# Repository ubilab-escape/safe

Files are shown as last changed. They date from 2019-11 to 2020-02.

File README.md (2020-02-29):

# Team Safe and Puzzles

## Motivation:
The Players are told to steal the Prototype from the Lab. The Prototype will be locked in the safe.

## General Idea:
After Entering the Lab Room the safe will be deactivated (red LED light). The players first have to supply the safe with power by solving a puzzle (see section puzzle).
This action will change the light color of the safes LED to orange and activate the second puzzle. This puzzle will ultimately open the safe to give access to the prototype.

## Puzzles:
### Puzzle to activate the safe: 
* Switching levers in correct position
* Find the correct resistor to generate the correct voltage

### Puzzle to open the safe:
* Riddle with numpad input

## Partlist

**part**|**count**|**price/part in €**|**price total**|**link**
:-----:|:-----:|:-----:|:-----:|:-----:
Keypad|1|5.8|5.8|[Octopart](https://octopart.com/3845-adafruit+industries-94636475?r=sp&s=QRIaZTRmSZu4F2mVarnONA)
Solenoid Lock|1|13.35|13.35|[Octopart](https://octopart.com/1512-adafruit+industries-51880349?r=sp&s=Jx9Gw6qzSH2-PR3HbMgn8w)
Banana Plug|10|2.06|20.6|[Octopart](https://octopart.com/1325-2-pomona+electronics-55397240?r=sp&s=kmyIgsMeQOCZjpt9e\_rAXw)
Banana Socket|10|1.84|18.4|[Octopart](https://octopart.com/bu-00233-0-mueller-824050?r=sp&s=FBVoi6XFSGGoTvQtIDogQw)
Piezo Buzzer|5|1.03|5.15|[Octopart](https://octopart.com/mckpt-g1711a3-05-3691-multicomp-12157125?r=sp&s=TdKAcML0QkSYqrwuZLE5lQ)
Switch|8|2.17|17.36|[Octopart](https://octopart.com/100sp1t1b4m2qe-e-switch-1058620?r=sp&s=26ppMzJ4SaadG3iCrhg9HA)
N-MOS|10|0.7|7|[Octopart](https://octopart.com/irf510pbf-vishay-46532502?r=sp&s=Ft8oBWb7Tw--a\_FmfUap9w#)
Limit switches|2|1.81|3.62|[Octopart](https://octopart.com/db1c-b1lb-zf-71118816?r=sp&s=sDTxIuqxSJOc-Uf9S2HFEg)
Wooden chest|1|18|18|[Obi](https://www.obi.de/aufbewahrungsboxen/laublust-holzkiste-deckel-und-griffe-natur-kiefer-40-cm-x-30-cm-x-24-cm-fsc-/p/4480497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)
Total: 109.28 €

## Group

Markus Schwörer, Florian Bregler, Frank Mutter

## Protocol to control leds and piezo via mqtt

standart JSON message on topic 5/safe/control with data = "x:y". x is color and y is the mode.

Colors (x):
* LED_COLOR_WHITE 0
* LED_COLOR_RED 1
* LED_COLOR_GREEN 2
* LED_COLOR_BLUE  3
* LED_COLOR_ORANGE 4

Mode (y):
* LED_MODE_ON 0
* LED_MODE_OFF 1
* LED_MODE_PULSE 2
* LED_MODE_BLINK 3
* LED_MODE_PIEZO 9

For LED_MODE_PIEZO the color parameter is the time of the buzzer sound in seconds.

examples:
* "{\"method\": \"trigger\", \"state\": \"on\", \"data\": \"3:0\" }"
=> Turns blue LEDs on.
* "{\"method\": \"trigger\", \"state\": \"on\", \"data\": \"4:3\" }"
=> LEDs orange blinking.
* "{\"method\": \"trigger\", \"state\": \"on\", \"data\": \"5:9\" }"
=> Buzzer sound for 5 seconds (max value: 9)

## Schematics

### Safe Activate
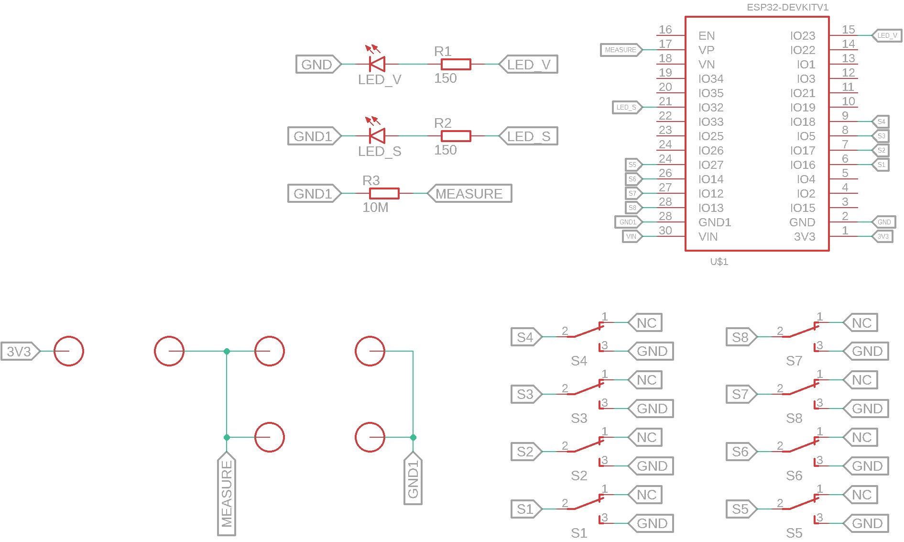
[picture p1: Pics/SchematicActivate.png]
Safe Activate Schematic

**Image 1**: Schematic of the activation.

### Safe Control
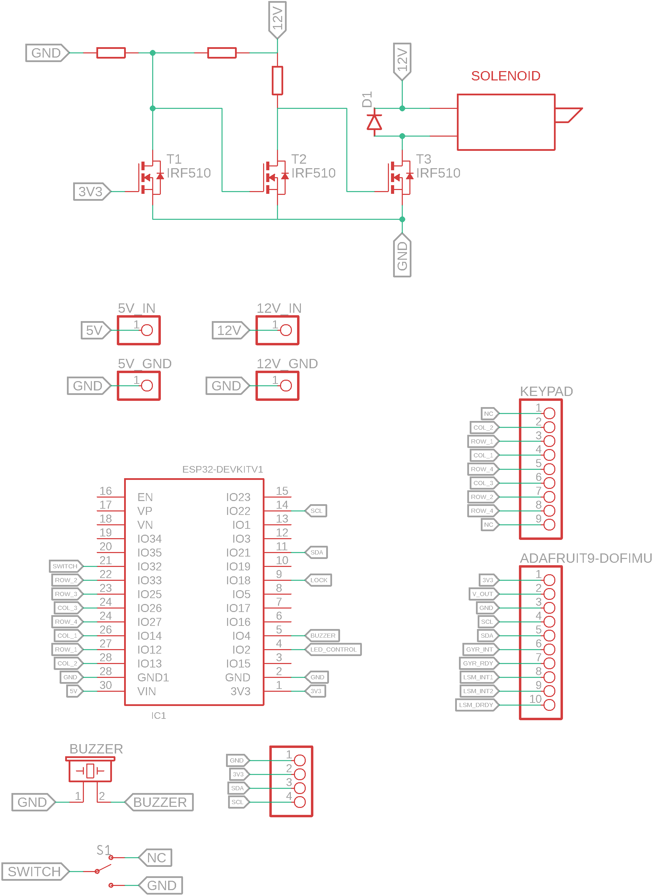
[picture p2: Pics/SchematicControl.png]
Safe Control Schematic

**Image 2**: Schematic of the safe.

## Flow Charts

### Safe Activate

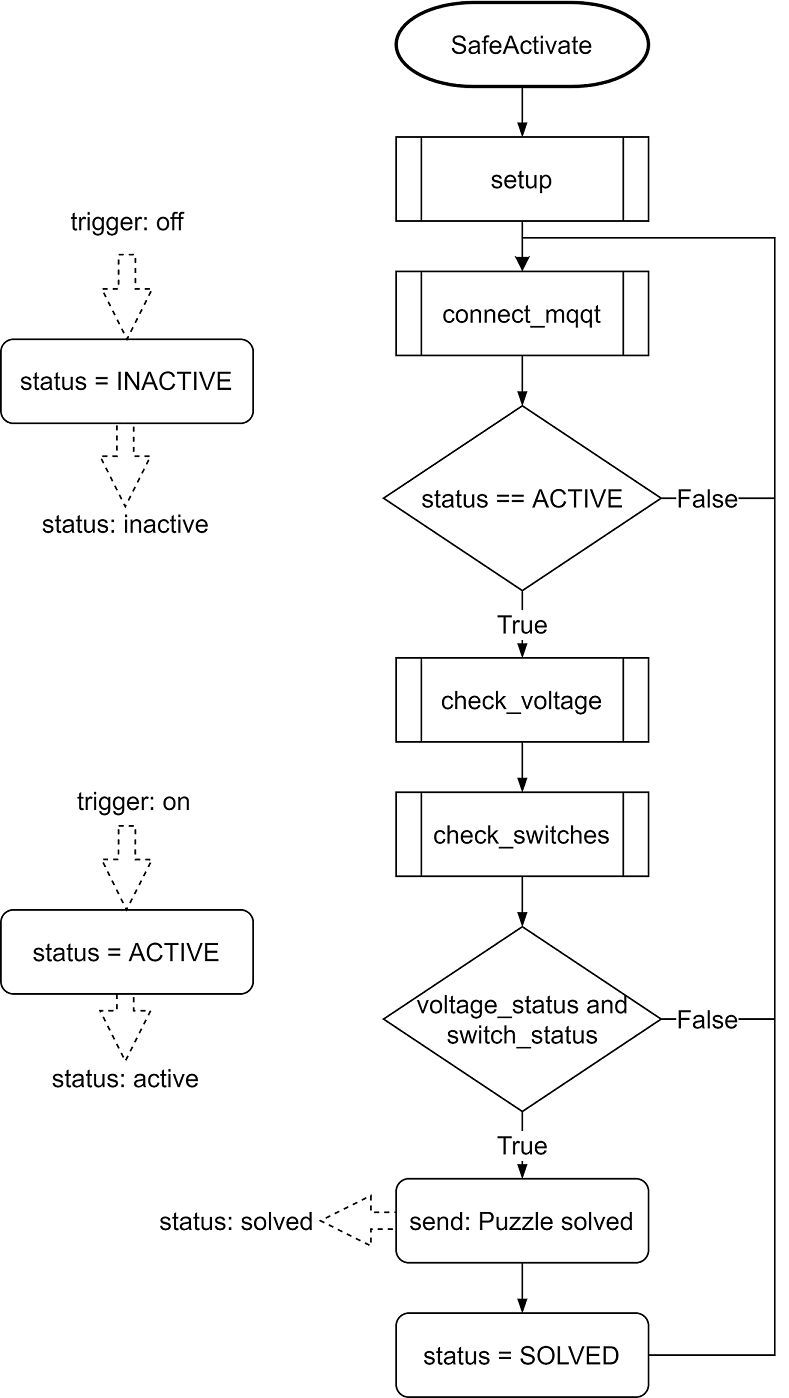
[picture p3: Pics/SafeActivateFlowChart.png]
Safe Activate Flow Chart


**Image 3**: Flow Chart of the safe activation

### Safe Control

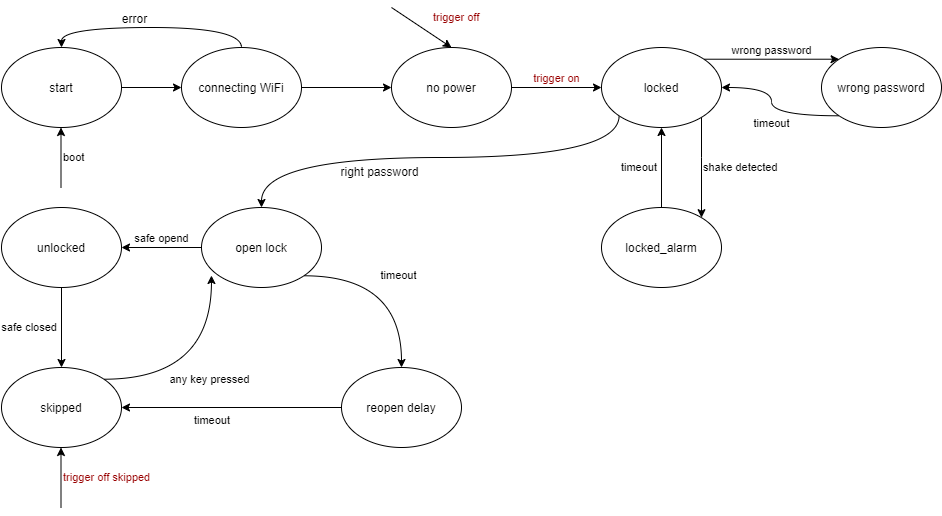
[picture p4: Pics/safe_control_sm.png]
Safe Control State Machine

**Image 4**: State machine of the safe control with the main states

## Instructions for the Escape Room Operator

### Room Reset:
* Close the safe 
* Pull out the resistors and place them in front of the puzzle
* Put the safe datasheet (back) on the table

# Pictures

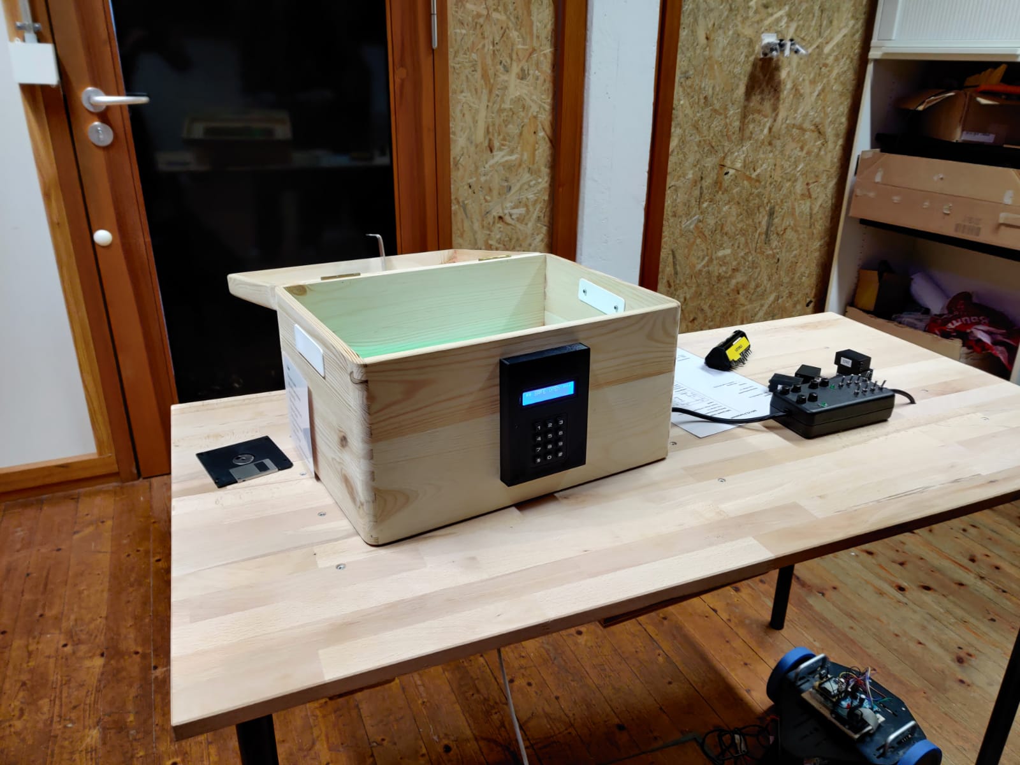
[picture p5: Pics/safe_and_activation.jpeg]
Safe and activation picture

**Image 5**: Picture of the safe (left) and the activatioin puzzle (right).

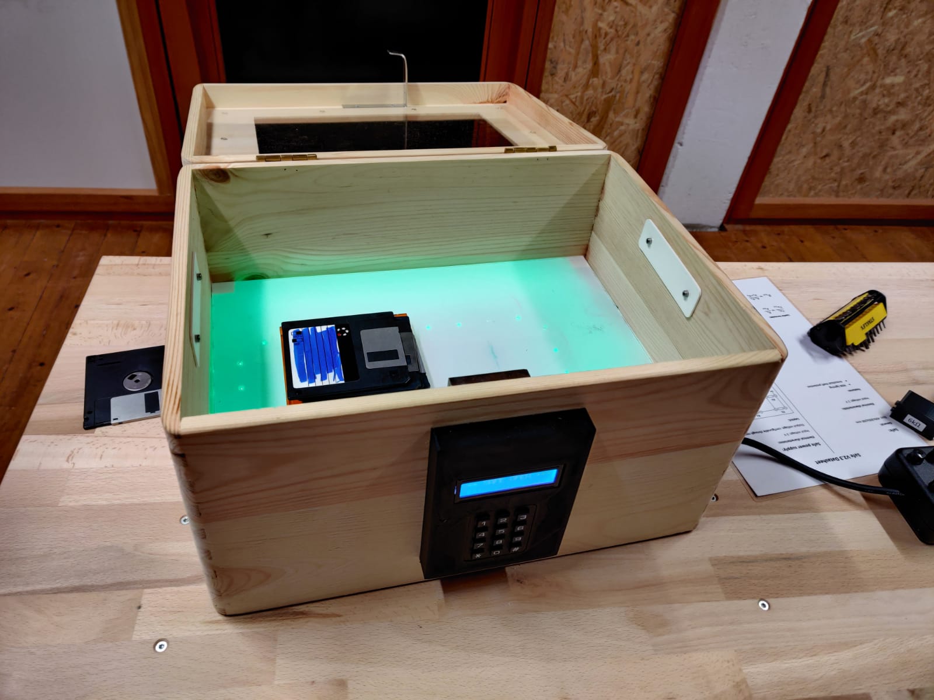
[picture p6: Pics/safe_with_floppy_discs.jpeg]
Safe with floppy discs

**Image 6**: Picture of the Safe with green LED color and floppy discs inside.

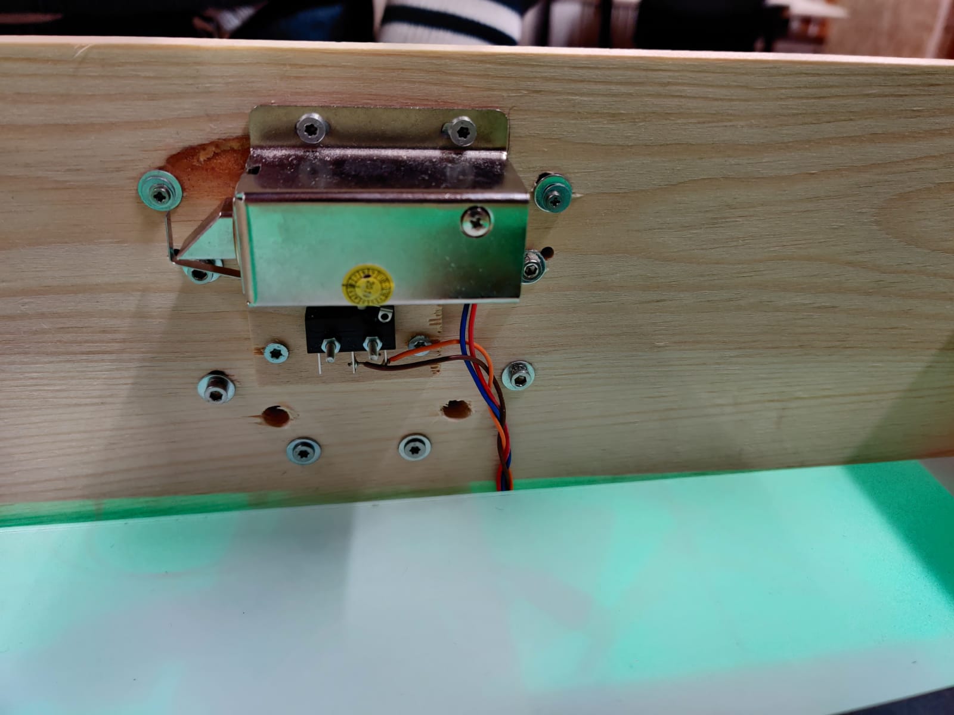
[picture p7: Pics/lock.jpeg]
lock with switch

**Image 7**: Picture of the lock with switch to detect whether the safe is opened or closed.

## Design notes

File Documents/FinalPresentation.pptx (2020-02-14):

## Group 5: Safe

Frank Mutter, Markus Schwörer, Florian Bregler

## Motivation

- Main story goal:
Players have to steal the Prototypes
- Safe:
Open safe → Get Prototypes

## Safe puzzle

- Divided into two parts:
1. Safe activation:
  - Voltage divider puzzle
  - Switch puzzle
2. Safe opening:
  - Code combination puzzle

## Safe activation

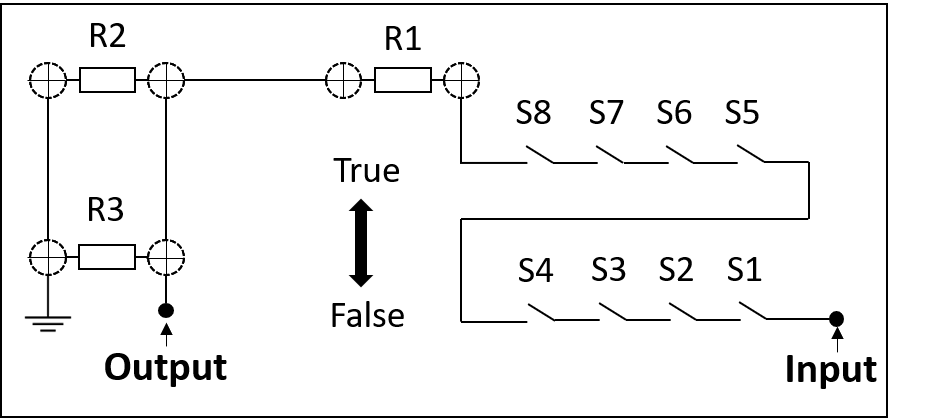
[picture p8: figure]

- Set switch position according to data sheet
- Divide input voltage using resistors

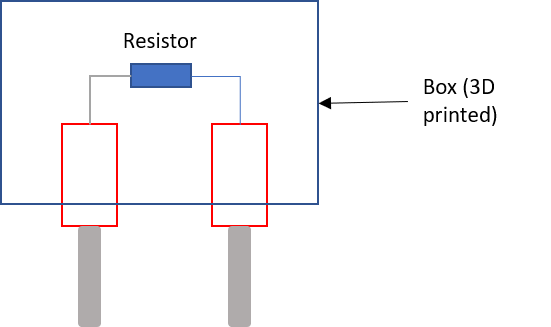
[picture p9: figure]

## Safe activation

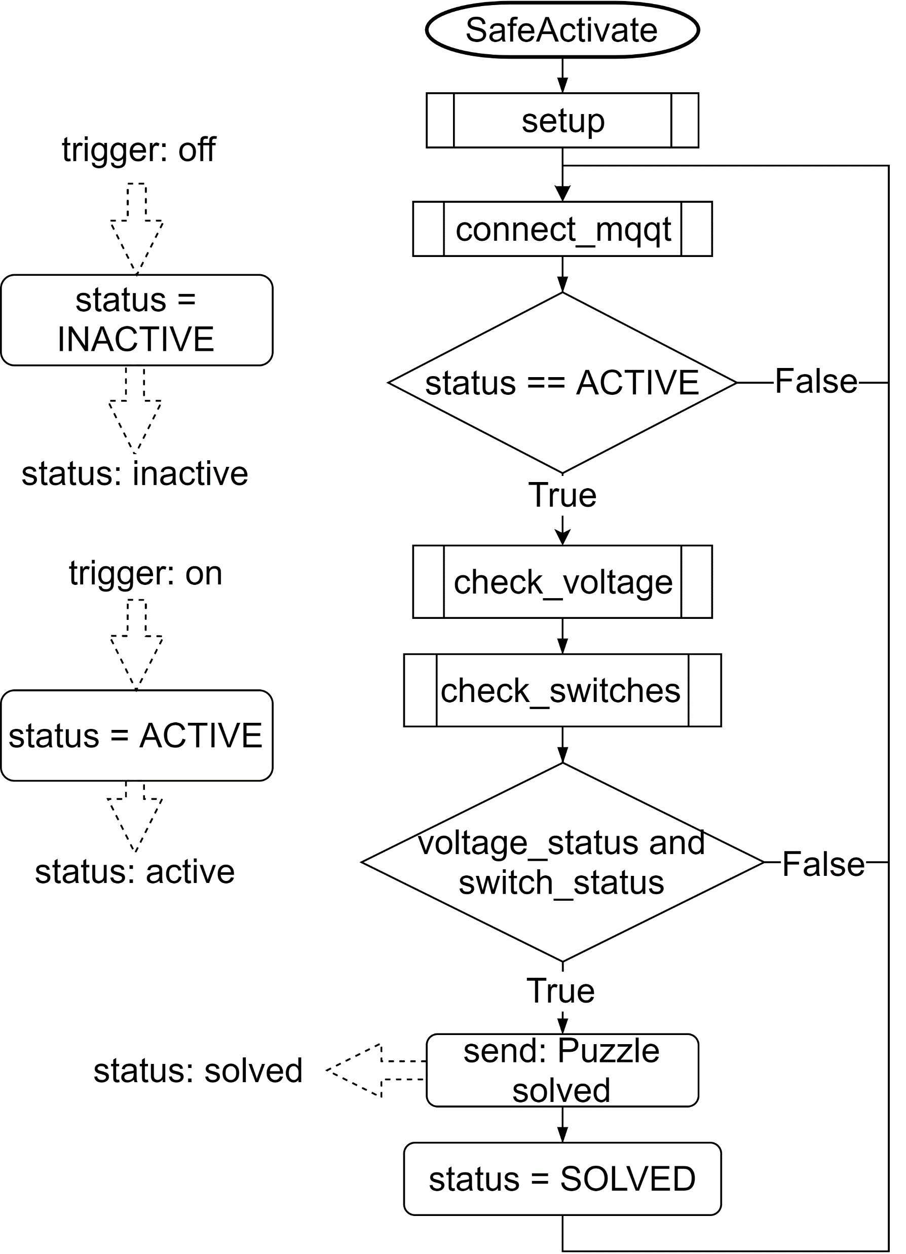
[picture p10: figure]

## Safe opening

## Live demo

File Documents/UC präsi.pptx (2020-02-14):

## team 5: safe

Markus Schwörer, Florian Bregle, Frank Mutter

## safe building

- wooden box; glueing acryl glass on top of it
- Use acrylic glass and a cnc mill
- Use a donation box like in the picture
-> replace the existent lock by electronic lock

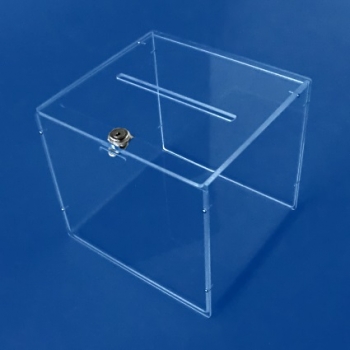
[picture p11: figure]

https://displayzentrum.net/images/product_images/info_images/losbox-schloss_2091_0.jpg; 7.11.19

## Puzzle - general idea

- safe has first to be connected to power lines -> one or two puzzles
  - Puzzles with „electronical“ background
- puzzle to open the safe -> one or two puzzles
=> Combine puzzles

## possible puzzles to activate the safe

- Find the correct resistor to generate the correct voltage
- Labelled with resistance
- Array of banana jacks

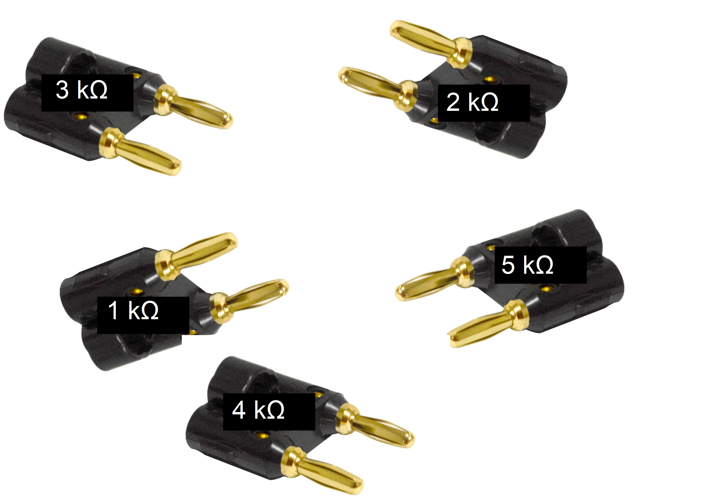
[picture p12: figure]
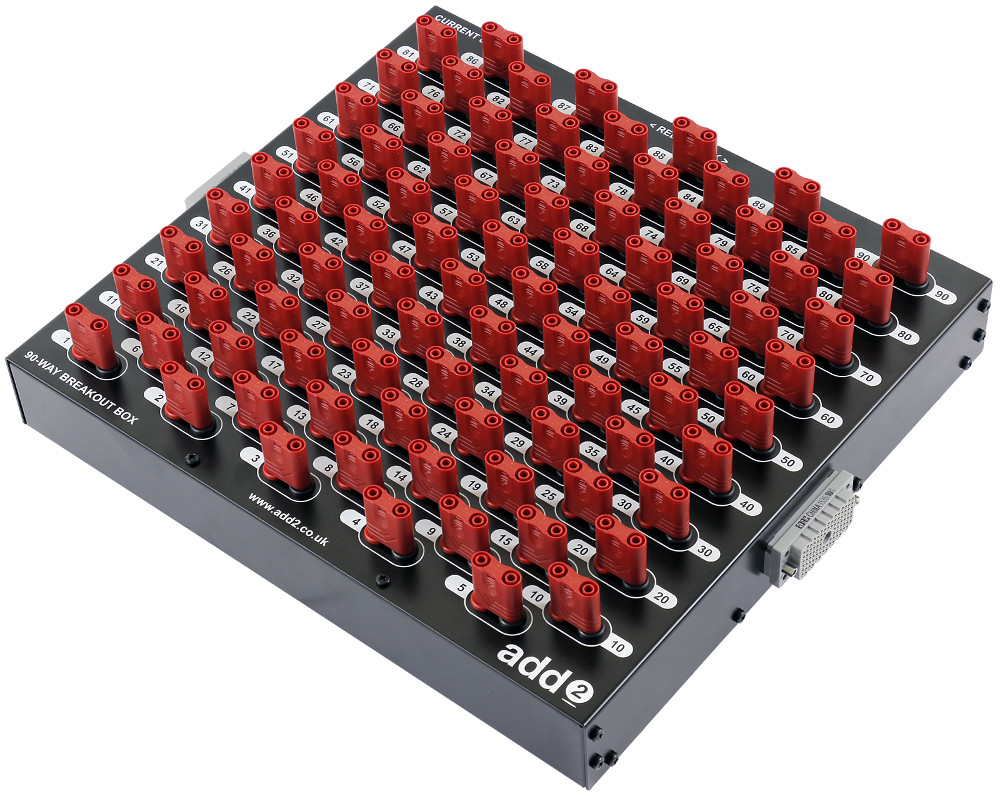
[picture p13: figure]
Ähnliches Foto

## possible puzzles to activate the safe

- Switching levers in correct order
- multiple puzzles with boolean answers

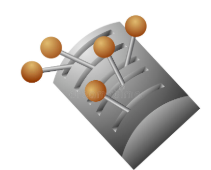
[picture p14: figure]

## possible puzzles to activate the safe

- Wiring cable riddle

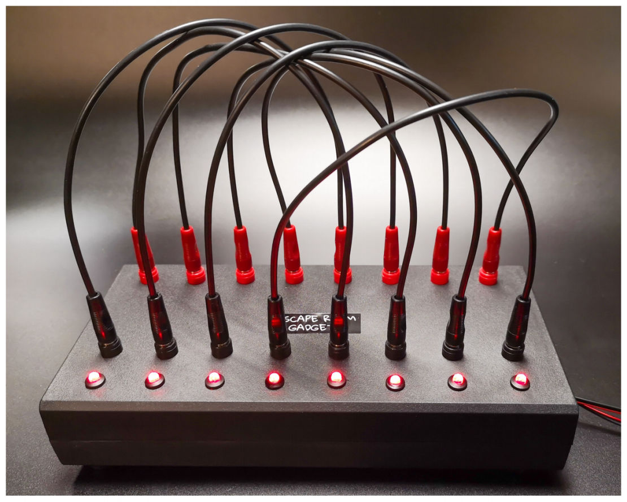
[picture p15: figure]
Mobirise

## possible puzzles to open the safe

- Riddle with numpad input
- Any riddle with a integer solution possible

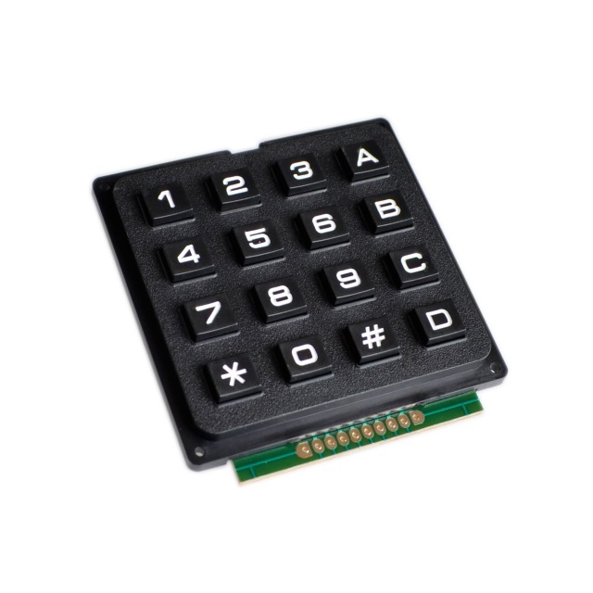
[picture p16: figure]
Bildergebnis für keypad

## possible puzzles to open the safe

- Find ID card of lab employee
  - Alternatively: magnetic stripe card
- Trick face recognition
  - Use NFC or QR Code for checking

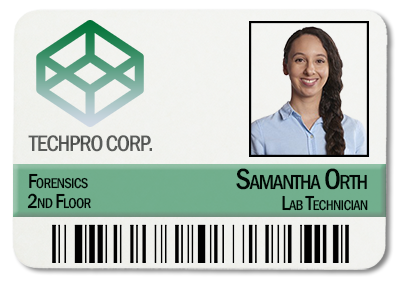
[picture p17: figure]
Bildergebnis für id card of lab

## possible puzzles to open the safe

Other ideas:
- Reach score in a little video game
  - Hard to fit in the story
- Activate sensor by using laser and movable mirrors

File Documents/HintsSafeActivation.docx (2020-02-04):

Hints for safe Activation Riddle

General:

Put the switches in the correct Position and divide the Input Voltage to the correct value for activating the safe

Voltage Divider:

Try to put the resistors in series and parallel to divide the voltage

Resistors in parallel decrease the resistance while resistors in series increase the overall resistance

Try to use two one kilo ohm resistors and one two kilo ohm resistor

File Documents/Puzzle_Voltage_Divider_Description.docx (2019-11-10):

Puzzle Voltage Divider:

Goal:

Players Should activate the safe, or activate the second activation Stage using this Puzzle

Task:

Player Should build one or multiple Voltage divider to reach a certain Output Voltage.

One or multiple Input Voltages will be provided.

Hints:

Input Voltage will be displayed somewhere on the device or in a Datasheet

Output Voltage will be displayed somewhere on the output device or in a Datasheet

Feedback of reaching goal:

Feedback will be given via LEDS

Material:

Banana Sockets (four)

Banana Plugs (two for every resistor)

Scheme of Puzzle:

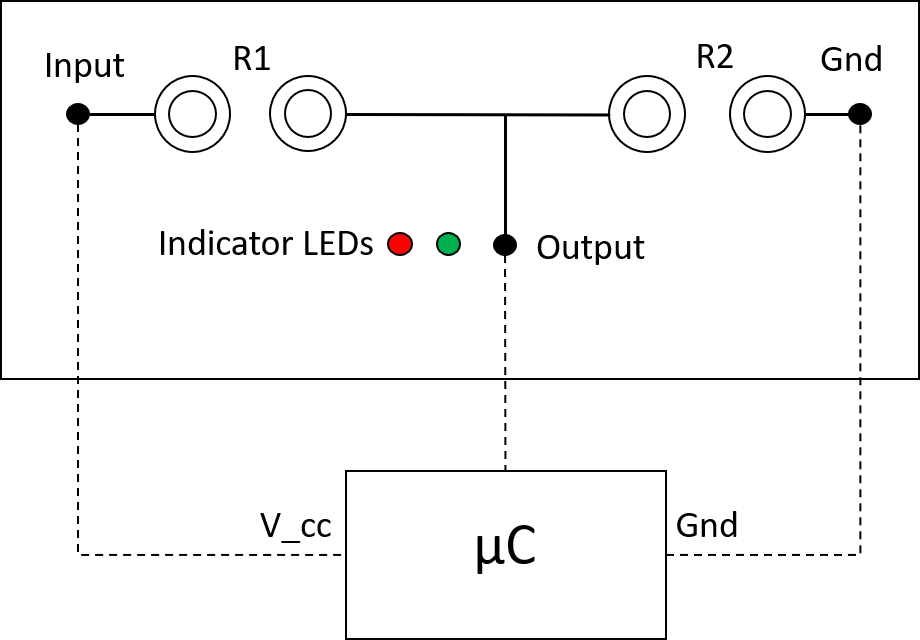
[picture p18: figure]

Resistors:


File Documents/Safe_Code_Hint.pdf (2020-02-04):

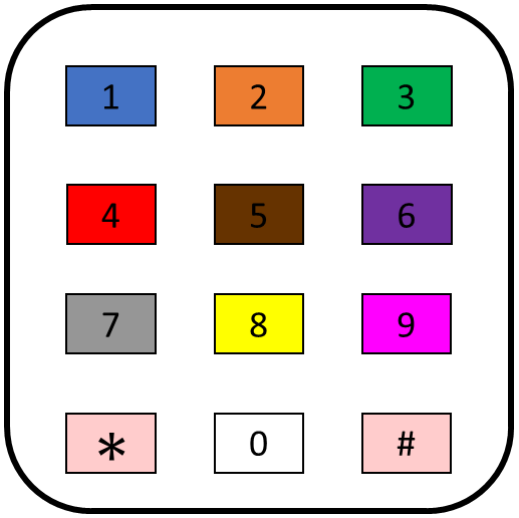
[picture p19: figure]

Color
The grass is green,
With small flowers between. The sky is blue
Where the clouds float thro‘. Pears are yellow,
Rich and ripe and mellow.
A Swan is white
Sailing in the light

Christina Georgina Rosseti

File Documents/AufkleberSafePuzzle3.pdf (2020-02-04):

2kΩ | 1kΩ | 1kΩ
6kΩ | 6kΩ

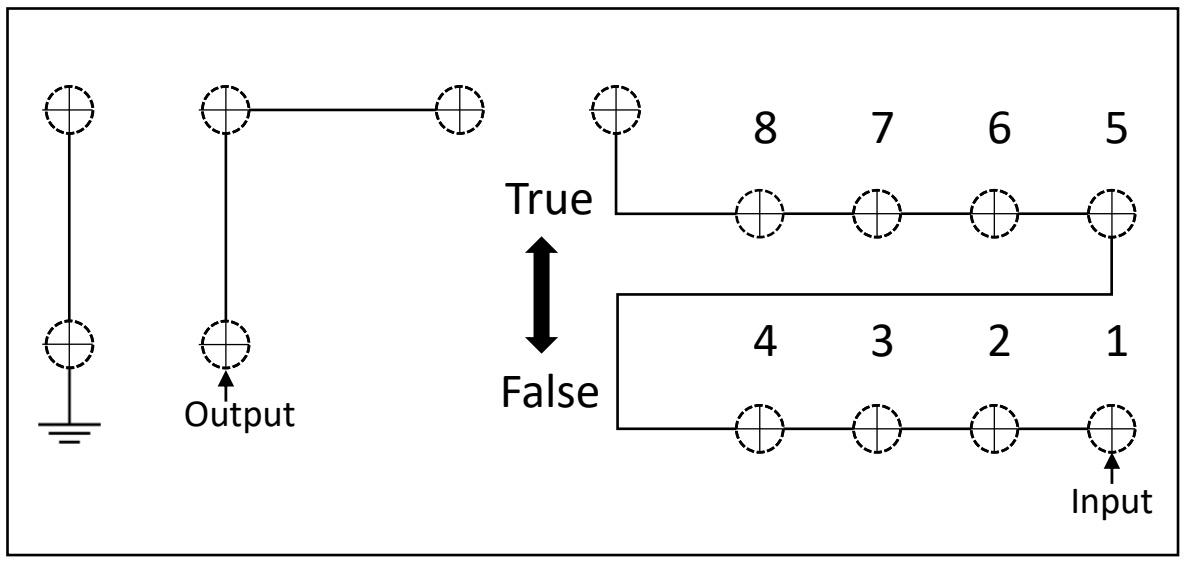
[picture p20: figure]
Output; Input; True; False

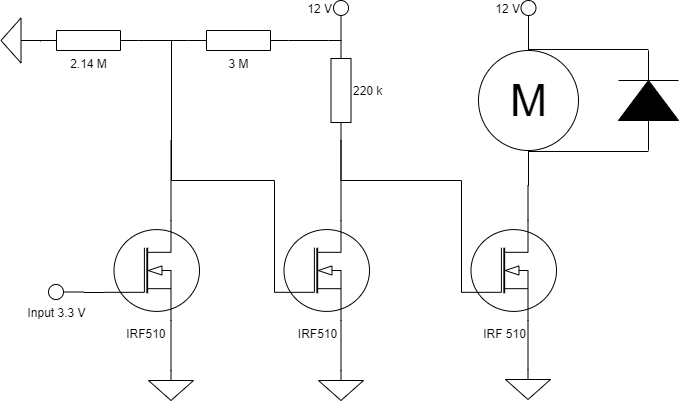
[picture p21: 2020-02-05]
Lock/transistor_circuit.png

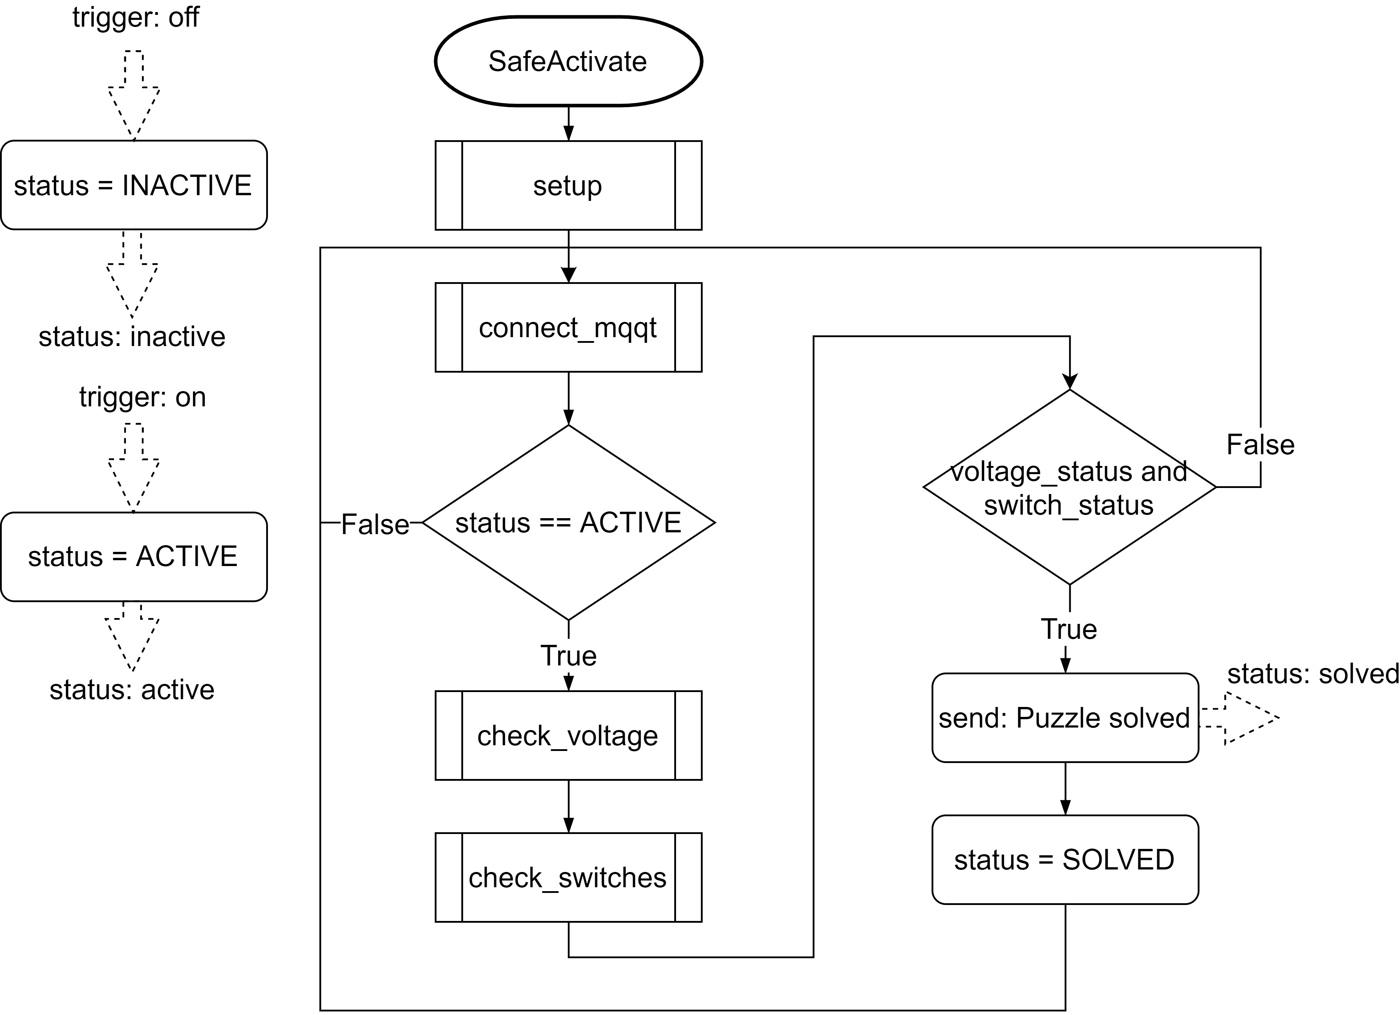
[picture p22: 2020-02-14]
FlowCharts/SafeActivateNewNew.png

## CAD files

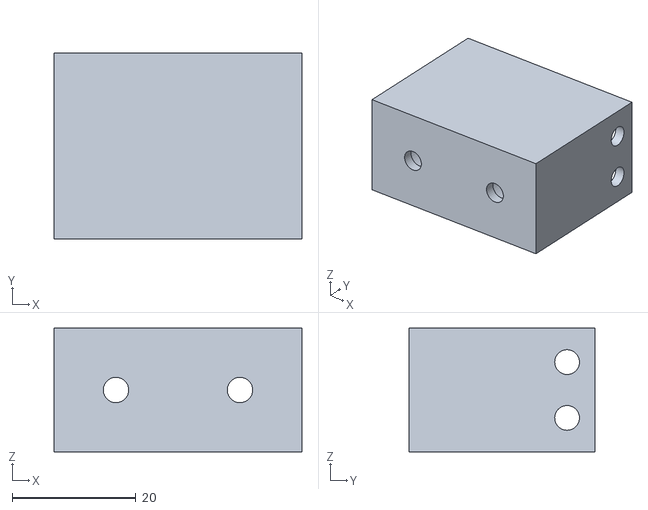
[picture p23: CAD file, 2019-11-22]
ResistorBox/Widerstandsbox v6.stl
40.0 x 30.0 x 20.0

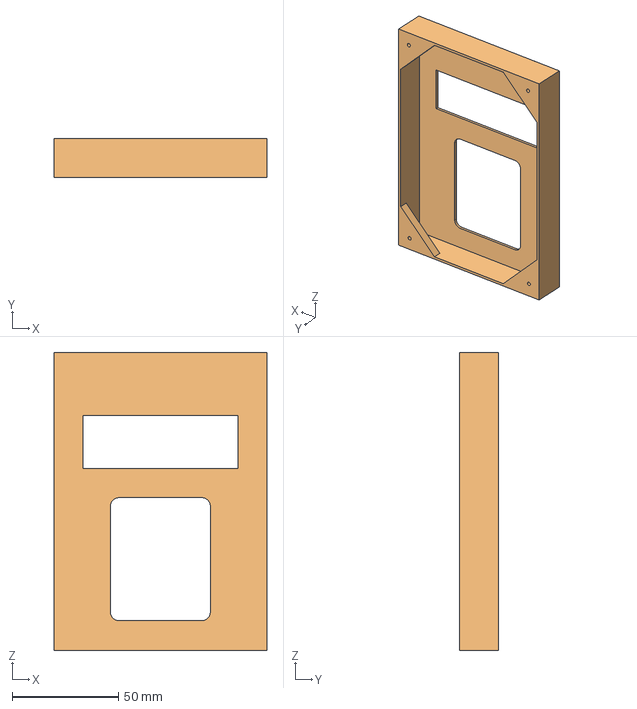
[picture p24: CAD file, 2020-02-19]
safe_cover/safe_coverV02.FCStd
100.0 x 18.5 x 140.0 mm

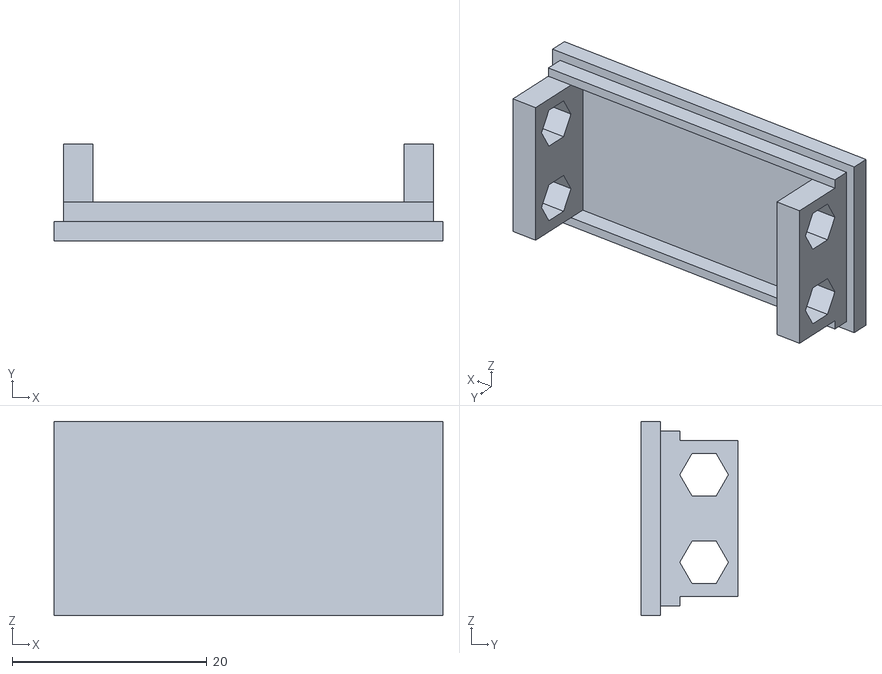
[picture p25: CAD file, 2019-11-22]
ResistorBox/Widerstandsbox_deckel v5.stl
40.0 x 10.0 x 20.0

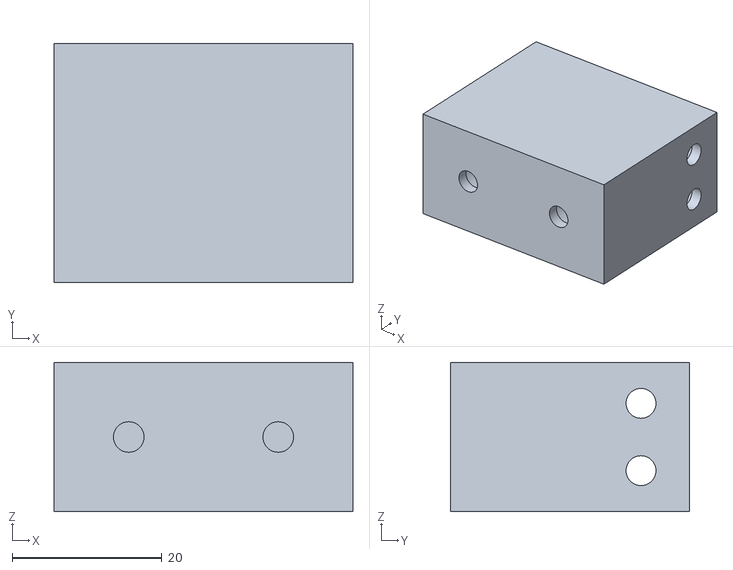
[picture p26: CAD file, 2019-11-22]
ResistorBox/Deckel+Box v3.stl
40.0 x 32.0 x 20.0

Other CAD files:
safe_cover/safe_coverV02.stl

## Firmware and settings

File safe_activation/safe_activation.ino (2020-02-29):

#include <PubSubClient.h>
#include <WiFi.h>
#include "esp_wifi.h"
#include <ESPmDNS.h>
#include <WiFiUdp.h>
#include <ArduinoOTA.h>
#include <Preferences.h>
#include <ArduinoJson.h>

// Placeholder for ssid and password read from ram
const char* key_ssid = "ssid";
const char* key_pwd = "pass";

WiFiClient espClient;
PubSubClient client(espClient);
Preferences preferences;

// Add your MQTT Broker IP address, example:
const char* mqtt_server = "10.0.0.2";

// Status messages
char* puzzleSolved_message = "{\"method\": \"status\", \"state\": \"solved\"}";
char* puzzleActive_message = "{\"method\": \"status\", \"state\": \"active\"}";
char* puzzleInactive_message = "{\"method\": \"status\", \"state\": \"inactive\"}";
StaticJsonDocument<300> mqtt_decoder;

#define S1 17
#define S2 16
#define S3 5
#define S4 18
#define S5 27
#define S6 14
#define S7 13
#define S8 12
#define LED_S_SOLVED 32
#define LED_V_SOLVED 23
#define MEASUREMENT_PIN A0
#define LOWER_THRESHOLD 500
#define HIGHER_THRESHOLD 700
#define AMOUNT_CORRECT_MEAS 5
#define WIFI_TIMEOUT_MS 3000

typedef enum
{
  STATE_INACTIVE = 0,
  STATE_ACTIVE = 1,
  STATE_SOLVED = 2,
  } puzzle_states;

typedef enum
{
  VOLT_SOLVED = 1,
  VOLT_NOT_SOLVED = 0,
  } voltage_states;

typedef enum
{
  SWITCH_SOLVED = 1,
  SWITCH_NOT_SOLVED = 0,
  } switch_states;
  
unsigned char switch_status;
unsigned char voltage_status;
unsigned char puzzle_status;
unsigned int adc_val;
unsigned int s1_val;
unsigned int s2_val;
unsigned int s3_val;
unsigned int s4_val;
unsigned int s5_val;
unsigned int s6_val;
unsigned int s7_val;
unsigned int s8_val;
unsigned int adc_correct_value;

void setup() {
  switch_status = SWITCH_NOT_SOLVED;
  voltage_status = VOLT_NOT_SOLVED;
  puzzle_status = STATE_ACTIVE;
  adc_val = 0;
  s1_val = 0;
  s2_val = 0;
  s3_val = 0;
  s4_val = 0;
  s5_val = 0;
  s6_val = 0;
  s7_val = 0;
  s8_val = 0;
  adc_correct_value = 0;
  // Init ADC GPIO
  pinMode(A0,INPUT);
  // Init GPIO for checking the switches
  pinMode(S1,INPUT_PULLUP);
  pinMode(S2,INPUT_PULLUP);
  pinMode(S3,INPUT_PULLUP);
  pinMode(S4,INPUT_PULLUP);
  pinMode(S5,INPUT_PULLUP);
  pinMode(S6,INPUT_PULLUP);
  pinMode(S7,INPUT_PULLUP);
  pinMode(S8,INPUT_PULLUP);
  pinMode(LED_S_SOLVED,OUTPUT); digitalWrite(LED_S_SOLVED,HIGH);
  pinMode(LED_V_SOLVED,OUTPUT); digitalWrite(LED_V_SOLVED, HIGH);
  Serial.begin(9600);
  setup_wifi();
  initOTA();
  client.setServer(mqtt_server, 1883);
  client.setCallback(callback);
}

void loop() {
  // Debug output current state
  //Serial.print("Current State:"); Serial.println(puzzle_status); 
  // Always connect to the mqqt server
  connect_mqqt();
  if(puzzle_status == STATE_ACTIVE){  
    // Check wether puzzle are solved
    voltage_status = check_voltage();
    switch_status = check_switches();
    // Publish solved Message once if both parts are solved 
    if(!(puzzle_status == STATE_SOLVED)){
      if(voltage_status  && switch_status){
        Serial.println("Both puzzles solved");
        client.publish("5/safe/activate", puzzleSolved_message, true);
        puzzle_status = STATE_SOLVED;
      }
    }
  }
  ArduinoOTA.handle();
}

// Function returning 1 when switches are in the correct position
unsigned int check_switches(){
    s1_val = digitalRead(S1);
    s2_val = digitalRead(S2);
    s3_val = digitalRead(S3);
    s4_val = digitalRead(S4);
    s5_val = digitalRead(S5);
    s6_val = digitalRead(S6);
    s7_val = digitalRead(S7);
    s8_val = digitalRead(S8);
  /*
  // Debug output
  Serial.print("S1: ");  Serial.println(s1_val);
  Serial.print("S2: ");  Serial.println(s2_val);
  Serial.print("S3: ");  Serial.println(s3_val);
  Serial.print("S4: ");  Serial.println(s4_val);
  Serial.print("S5: ");  Serial.println(s5_val);
  Serial.print("S6: ");  Serial.println(s6_val);
  Serial.print("S7: ");  Serial.println(s7_val);
  Serial.print("S8: ");  Serial.println(s8_val);
  */
  // If switches are in the correct position set status LED to High
  if(!s2_val && !s3_val && !s6_val && !s8_val && s1_val && s4_val && s5_val && s7_val){
    Serial.println("Puzzle Switches Solved");
    delay(200);
    digitalWrite(LED_S_SOLVED,HIGH);
    return SWITCH_SOLVED;
  }
  else{
    delay(200);
    digitalWrite(LED_S_SOLVED,LOW);
    return SWITCH_NOT_SOLVED;
  }
}

// returns 1 when sensing the correct voltage
unsigned int check_voltage(){
  adc_val = analogRead(A0);
  // Debug output
  //Serial.print("ADC VAL: "); Serial.println(adc_val);
  // Turn on led and return 1 if measured voltage is between Thresholds
  if((adc_val < HIGHER_THRESHOLD) && (adc_val > LOWER_THRESHOLD)){
    adc_correct_value = adc_correct_value + 1;
    // Only return solved when there are a least 5 consecutive measurements in the right voltage range
    if(adc_correct_value > AMOUNT_CORRECT_MEAS){
        digitalWrite(LED_V_SOLVED,HIGH);
        Serial.println("Puzzle Voltage Solved");
        adc_correct_value = 0;
        return VOLT_SOLVED;
    }
    else{
      return VOLT_NOT_SOLVED;
    }
  }
  else{
    digitalWrite(LED_V_SOLVED,LOW);
    adc_correct_value = 0;
    return VOLT_NOT_SOLVED;
  }
  return VOLT_NOT_SOLVED;
}


void setup_wifi() {
  delay(10);
  // Connect to selected WiFi Network
  Serial.println();
  Serial.print("Connecting");
  int timeout_start = millis();
  char ssid[30];
  char wlan_password[30];
  preferences.begin("wifi", false); 
  // Get password and ssid from ram
  preferences.getString(key_pwd, wlan_password, 30);
  preferences.getString(key_ssid, ssid, 30);
  preferences.end();
  WiFi.begin(ssid, wlan_password);
  while (WiFi.status() != WL_CONNECTED) {
    delay(500);
    Serial.print(".");
      // Restart ESP when no connection to the Network is established
     if (timeout_start + WIFI_TIMEOUT_MS < millis()) {
      ESP.restart();
    }
  }
  // Turn LED off to signalise that the device is connected to the Network
  digitalWrite(LED_S_SOLVED,LOW);
  digitalWrite(LED_V_SOLVED, LOW);
  Serial.println("");
  Serial.println("WiFi connected");
  Serial.print("IP address: ");
  Serial.println(WiFi.localIP());
}

void initOTA() {
  ArduinoOTA.setHostname("5/safe_activation");
  ArduinoOTA
    .onStart([]() {
      String type;
      if (ArduinoOTA.getCommand() == U_FLASH)
        type = "sketch";
      else // U_SPIFFS
        type = "filesystem";

      // NOTE: if updating SPIFFS this would be the place to unmount SPIFFS using SPIFFS.end()
      Serial.println("Start updating " + type);
    })
    .onEnd([]() {
      Serial.println("\nEnd");
    })
    .onProgress([](unsigned int progress, unsigned int total) {
      Serial.printf("Progress: %u%%\r", (progress / (total / 100)));
    })
    .onError([](ota_error_t error) {
      Serial.printf("Error[%u]: ", error);
      if (error == OTA_AUTH_ERROR) Serial.println("Auth Failed");
      else if (error == OTA_BEGIN_ERROR) Serial.println("Begin Failed");
      else if (error == OTA_CONNECT_ERROR) Serial.println("Connect Failed");
      else if (error == OTA_RECEIVE_ERROR) Serial.println("Receive Failed");
      else if (error == OTA_END_ERROR) Serial.println("End Failed");
    });
    ArduinoOTA.begin();
}

// Mqqt callback function
void callback(char* topic, byte* payload, unsigned int length) {
    Serial.print("Received message [");
    Serial.print(topic);
    Serial.print("] ");
    char msg[length+1];
    for (int i = 0; i < length; i++) {
        Serial.print((char)payload[i]);
        msg[i] = (char)payload[i];
    }
    Serial.println();
 
    msg[length] = '\0';
    Serial.println(msg);
    // Deserialzie messafe
    deserializeJson(mqtt_decoder, msg);
    const char* method_msg = mqtt_decoder["method"];
    const char* state_msg = mqtt_decoder["state"];
    const char* data_msg = mqtt_decoder["data"];
    Serial.println(method_msg);
    Serial.println(state_msg);
    Serial.println(strcmp(method_msg, "trigger") == 0);
    Serial.println(strcmp(state_msg, "on") == 0);
    // If trigger on message was sended
    if(strcmp(topic, "5/safe/activate") == 0 && strcmp(method_msg, "trigger") == 0 && strcmp(state_msg, "on") == 0){
      puzzle_status = STATE_ACTIVE;
      client.publish("5/safe/activate", puzzleActive_message, true);
    }
   // If trigger off message was sended
    if(strcmp(topic, "5/safe/activate") == 0 && strcmp(method_msg, "trigger") == 0 && strcmp(state_msg, "off") == 0){
      puzzle_status = STATE_INACTIVE;
      client.publish("5/safe/activate", puzzleInactive_message, true);
    }  
}

// Function connecting to the mqqt server and suscribing the topic
void connect_mqqt(){
	client.loop();
  while (!client.connected()){
    Serial.println("no connection");
    client.connect("SafeActivation");
    client.subscribe("5/safe/activate");
  }
}

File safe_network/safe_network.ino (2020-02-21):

/* 
 * call once to save credentials in flash memory
 */
#include <Preferences.h>
#include <WiFi.h>
#include <ESPmDNS.h>
#include <WiFiUdp.h>
#include <ArduinoOTA.h>

Preferences preferences;
const char* key_ssid = "ssid";
const char* ssid = "...";              // <-------- enter the ssid of your network

const char* key_WifiPassword = "pass";
const char* wifiPassword = "...";     // <--------- enter the password for your network

const char* key_safeCode = "safeCode";
const char* safeCode = "...";         // <---------- enter the safe code you want


void setup() {
  Serial.begin(115200);
  Serial.print("writing credentials into eeprom ");
  preferences.begin("wifi", false); 
  Serial.print(".");
  preferences.putString(key_WifiPassword, wifiPassword);
  Serial.print(".");
  preferences.putString(key_ssid, ssid);
  Serial.print(".");
  preferences.putString(key_safeCode, safeCode);
  Serial.print(".");
  preferences.end();
  Serial.println(" Done");
  Serial.println("Trying to connect to wifi...");
  WiFi.mode(WIFI_STA);
  WiFi.begin(ssid, wifiPassword);
  while (WiFi.waitForConnectResult() != WL_CONNECTED) {
    Serial.println("Connection Failed! Rebooting...");
    delay(5000);
    ESP.restart();
  }
  Serial.println("Initializing update over the air...");
  ArduinoOTA.setHostname("5/safe_updateCredentials");
  ArduinoOTA
    .onStart([]() {
      String type;
      if (ArduinoOTA.getCommand() == U_FLASH)
        type = "sketch";
      else // U_SPIFFS
        type = "filesystem";
      Serial.println("Start updating " + type);
    })
    .onEnd([]() {
      Serial.println("\nEnd");
    })
    .onProgress([](unsigned int progress, unsigned int total) {
      Serial.printf("Progress: %u%%\r", (progress / (total / 100)));
    })
    .onError([](ota_error_t error) {
      Serial.printf("Error[%u]: ", error);
      if (error == OTA_AUTH_ERROR) Serial.println("Auth Failed");
      else if (error == OTA_BEGIN_ERROR) Serial.println("Begin Failed");
      else if (error == OTA_CONNECT_ERROR) Serial.println("Connect Failed");
      else if (error == OTA_RECEIVE_ERROR) Serial.println("Receive Failed");
      else if (error == OTA_END_ERROR) Serial.println("End Failed");
    });
  ArduinoOTA.begin();
  Serial.println("Update ota started.");
}

void loop() {
  // esp_wifi_set_ps(WIFI_PS_NONE); // disable power saving features for better ping; probably not needed here
  ArduinoOTA.handle();
}

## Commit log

2019-11-10 Added description of Voltage Divider Puzzle
2019-11-13 added vibration sensor and switches
2019-11-22 Added CAD Files of resistor box
    [Deckel+Box v3.stl, Widerstandsbox v6.stl, Widerstandsbox_deckel v5.stl]
2019-12-13 changed pin layout for ESP32
2020-01-08 added OTA; ESP is working with I2C LCD now; rebuilt functions for printing status & password on the LCD; added lock & timer to prevent overheating;
    [safe.ino]
2020-01-08 working wiring with three IRF510 transistors
2020-01-08 added speaker alarm; added acceleration sensor; added first MQTT functionality;
2020-01-09 Added Arduino Code for safe activation
2020-01-14 added leds code
2020-01-14 fixed mqtt message; moved most of the code in the loop function to its own function
    [safe.ino]
2020-01-14 integration and fixed some bugs
    [safe.ino]
2020-01-14 fixed some more bugs
    [safe.ino]
2020-01-14 removed blocking part for accelerometer
2020-01-15 json char* compare bug fixes
    [safe.ino]
2020-01-15 fixed bug: lock is now off when countdown finished;
    [safe.ino]
2020-01-16 Added second LED
2020-01-21 added led/piezo control via mqtt
2020-01-21 bugfix in led/piezo control via mqtt
    [safe.ino]
2020-01-21 added led/piezo protocoll to readme
2020-01-24 deleted some TODOs; added missing "}"
    [safe.ino]
2020-01-27 added "debug mode" without wlan for testing keypad, LEDs and lock opening; closing lock should now not be able to trigger the acceleration sensor; WARNING: this code was not tested!
2020-01-28 Changed from Interrupt to polling
2020-01-28 bugfix in read out credentials from flash memory
    [safe.ino]
2020-01-29 fixed a bug, trigger on/off is working now
    [safe.ino]
2020-01-29 "trigger" now lower case; removed pin code for arduino;
2020-01-30 Changed Json format from upper case to Lower
2020-01-30 safe_network: added update OTA; TODO: why is it not working in the ubilab wifi???; safe.ino: bug fixes: saving pin code in eeprom working now;
    [safe.ino, safe_network.ino]
2020-02-04 changed led stuff and added skipped state
    [safe.ino]
2020-02-04 added two new safe states: once the code is typed in the safe can be opened with one arbitrary key again; to prevent the lock from overheating some delay between two opening tries is added; fixed typ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
    [safe.ino]
2020-02-05 fixed a small bug
    [safe.ino]
2020-02-05 changed transistor circuit diagram
2020-02-11 changed library for LEDs; try to connect to wifi 2 times before restarting esp
2020-02-11 added safe activate schematic
2020-02-11 Added schematic for safe control
2020-02-13 Updated Flowchart + Read me
2020-02-13 Added Flow Charts
2020-02-14 cleanup, added flowchart, added poresentation with macros
2020-02-14 fixed skipping power activation puzzles bug; started to split code and to add comments;
    [safe.ino]
2020-02-19 added the safe cover model in .stl and .FCStd (FreeCAD)
    [safe_coverV02.FCStd, safe_coverV02.stl]
